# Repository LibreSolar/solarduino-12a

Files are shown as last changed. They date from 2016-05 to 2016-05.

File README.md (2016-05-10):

# Solarduino_12A
12A MPPT solar charge controller based on Arduino

Features: 
- 12A MPPT charger
- 55V max PV input
- 12V or 24V battery output
- Arduino-compatible (ATmega 328P used)
- Expandable via break-out of unused ports to standard 2.54 pin-pitch headers (e.g. used for display, communication like CAN/RS485, etc.)

Built-in protection:
- Overvoltage
- Undervoltage
- Overcurrent
- PV short circuit
- PV reverse polarity (for max. module open circuit voltage of around 40V)
- Battery reverse polarity (destructive, fuse is blown)

# Roadmap
- This is the new version of the charge controller. First PCB was sent to production beginning of May 2016. First test results end of May expected.

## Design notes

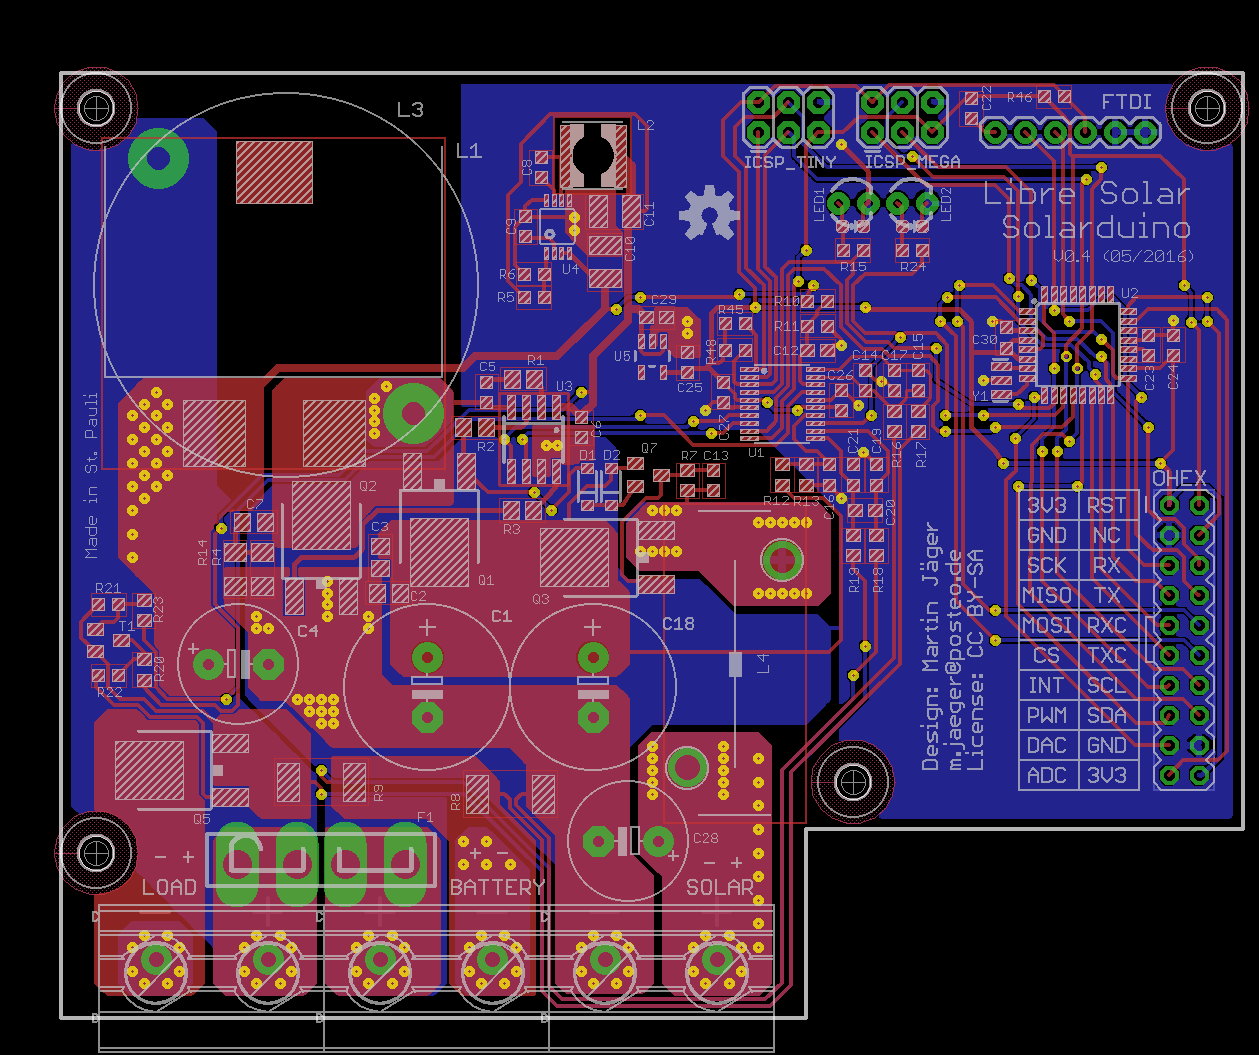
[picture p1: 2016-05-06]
Solarduino_V0.4.png

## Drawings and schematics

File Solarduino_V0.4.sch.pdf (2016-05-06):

A

A

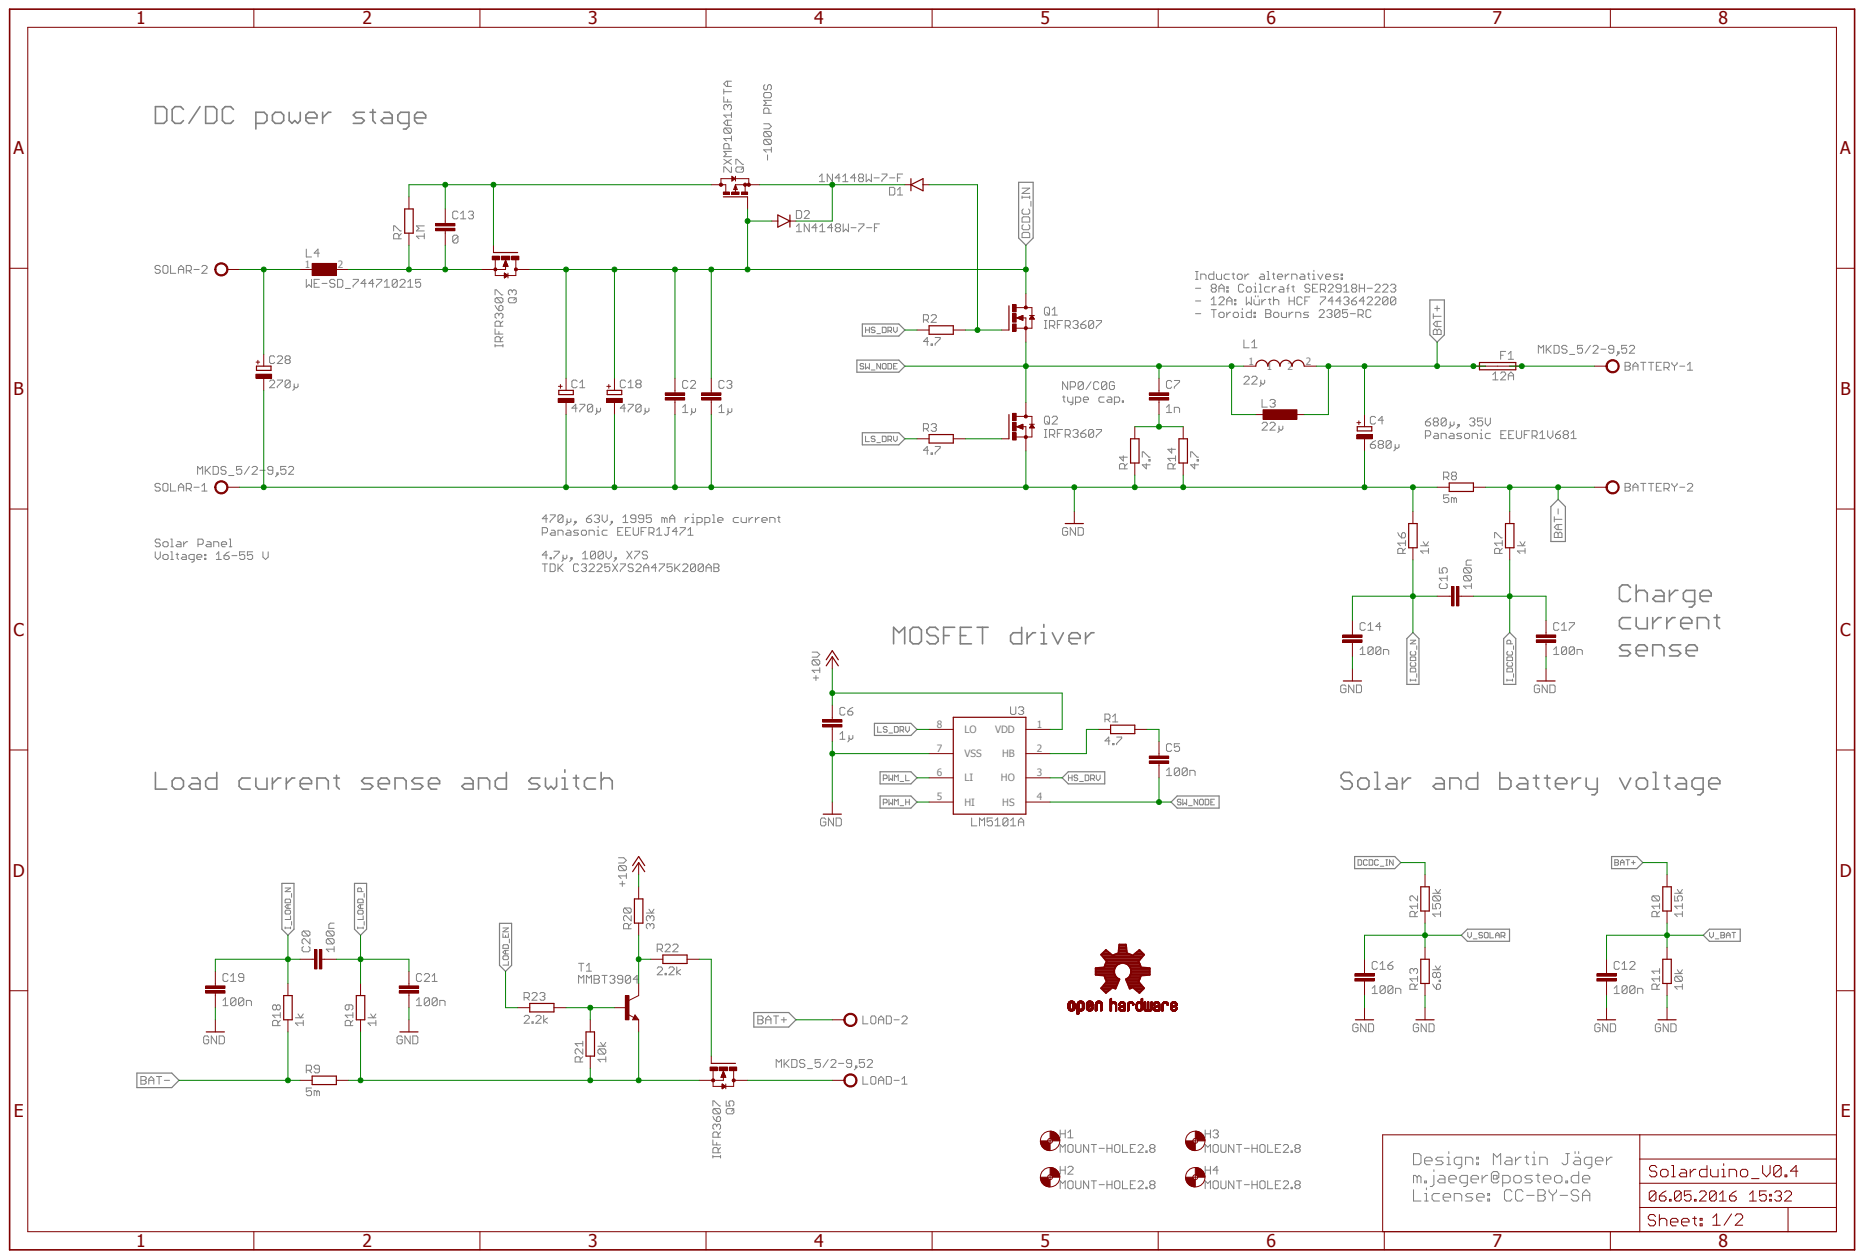
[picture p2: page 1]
VSS; 8 VDD

A

A

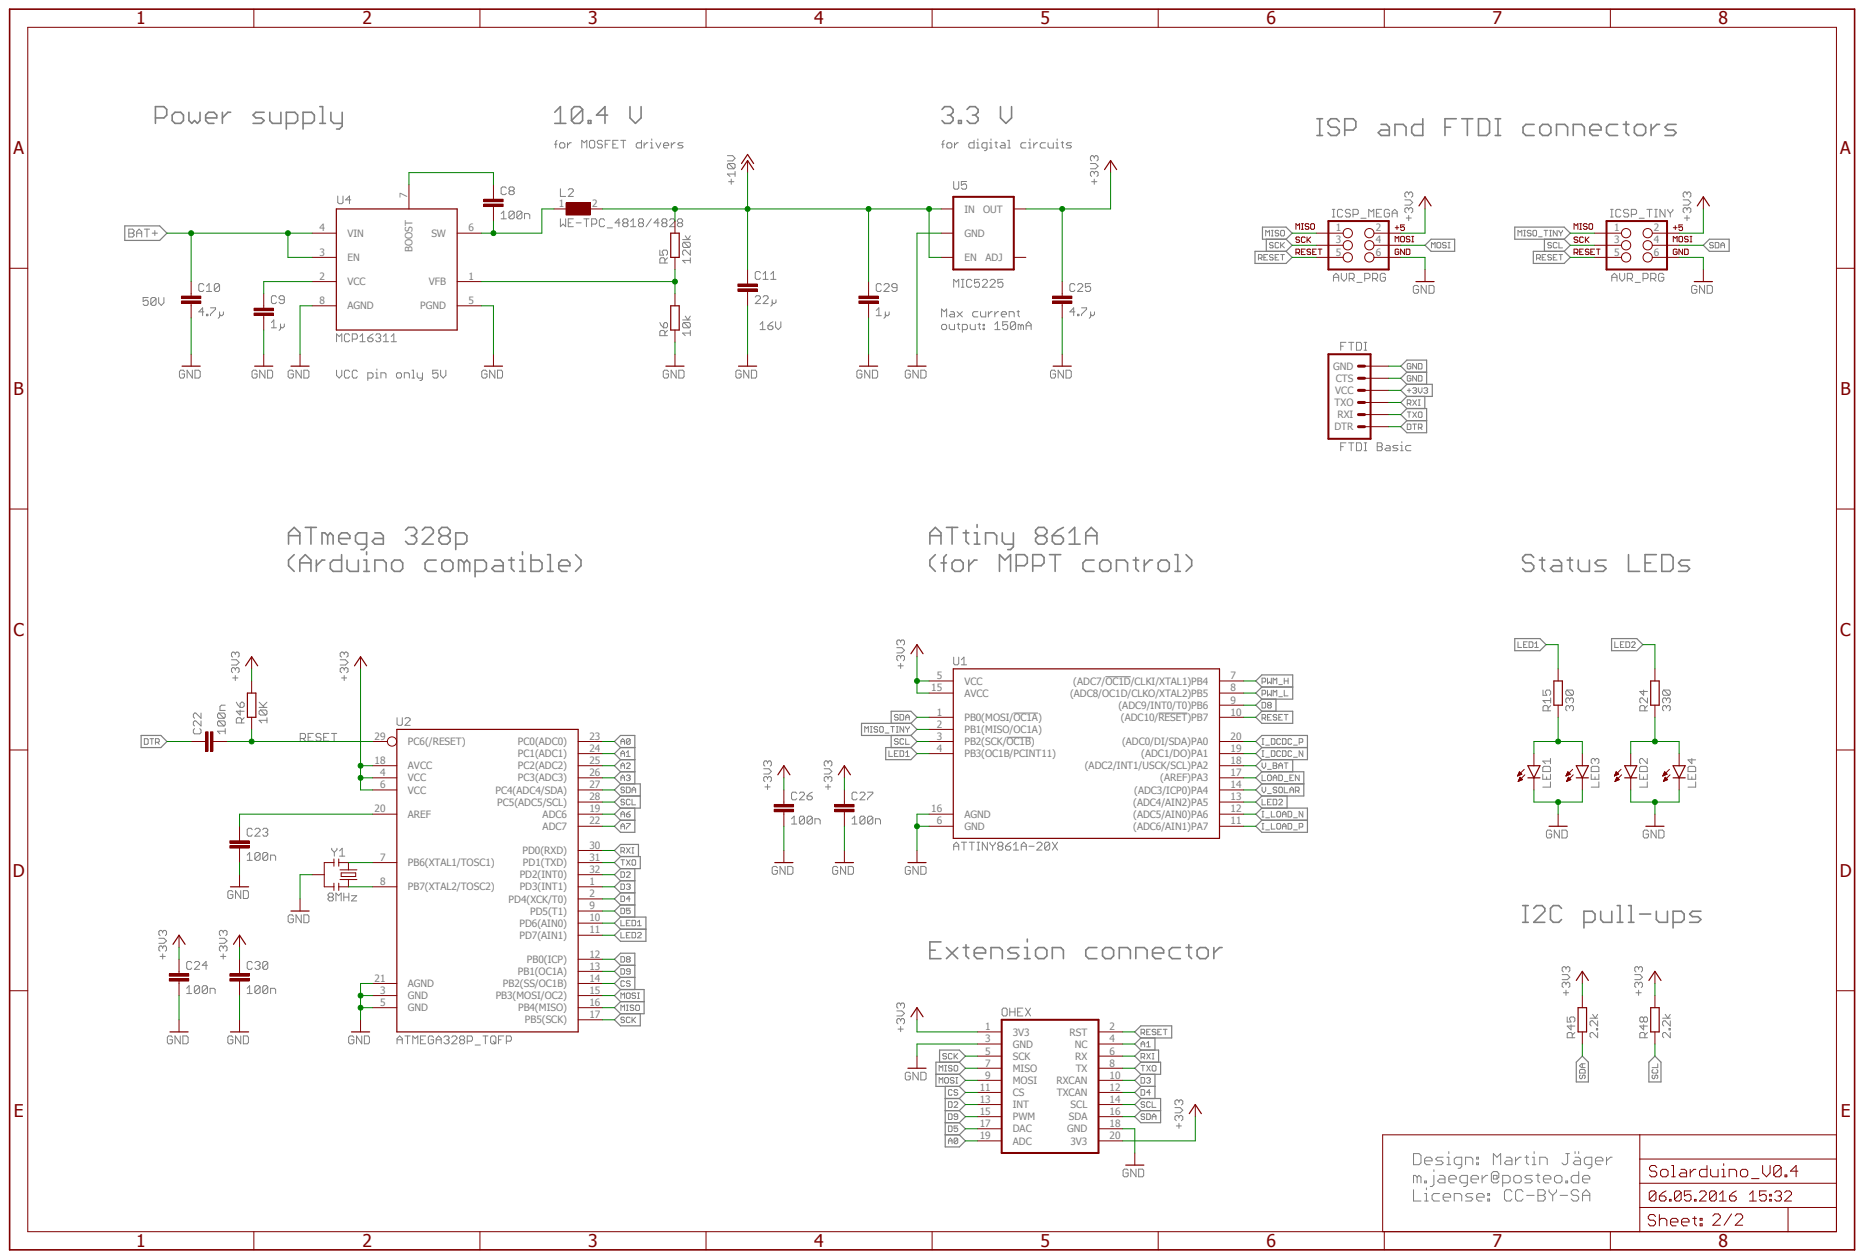
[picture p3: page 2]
DTR; RXI; TXO; VCC; CTS; GND; VFB; 1 VCC; VIN; PGND; BOOST; AGND; (ADC3/ICP0)PA4; (ADC4/AIN2)PA5; (ADC5/AIN0)PA6; (ADC6/AIN1)PA7; (AREF)PA3; 17 (ADC2/INT1/USCK/SCL)PA2; 18 (ADC1/DO)PA1; 19 (ADC0/DI/SDA)PA0; (ADC10/RESET)PB7; 10 (ADC9/INT0/T0)PB6; 9 (ADC8/OC1D/CLKO/XTAL2)PB5; 8 (ADC7/OC1D/CLKI/XTAL1)PB4; AVCC 15; AGND 16; PB0(MOSI/OC1A); PB1(MISO/OC1A); PB2(SCK/OC1B); PB3(OC1B/PCINT11); PB5(SCK); PB7(XTAL2/TOSC2); PB6(XTAL1/TOSC1); AGND 21; AREF 20; AVCC 18; PB4(MISO); 16 PB3(MOSI/OC2)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

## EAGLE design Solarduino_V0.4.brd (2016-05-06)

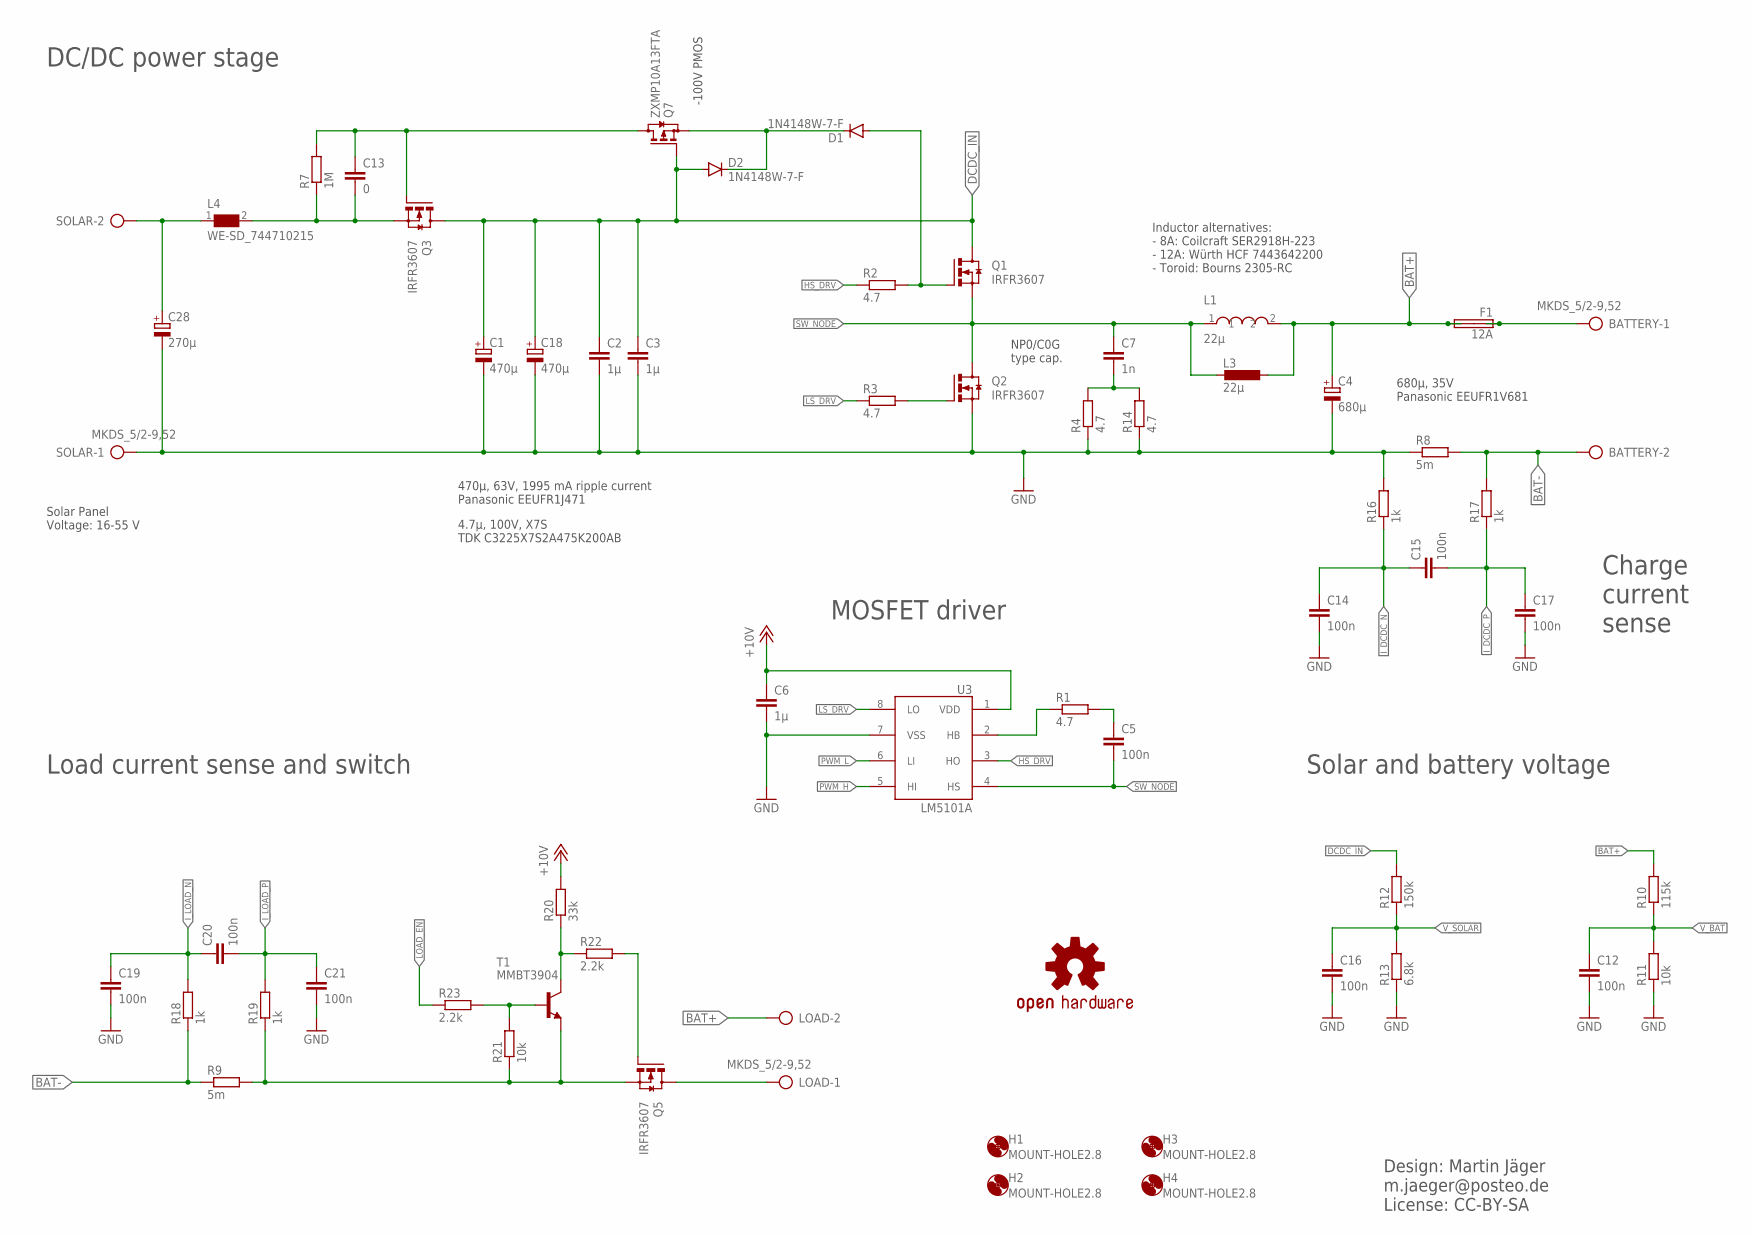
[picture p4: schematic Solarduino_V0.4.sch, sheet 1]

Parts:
BATTERY: MKDS_5/2-9,52; MKDS_5/2-952
C1, C18: 470µ; E5-13; MPN EEUFR1J331B
C2, C3: 1µ; C0805; MPN C3225X7S2A475K200AB
C4: 680µ; E5-10,5; MPN EEUFR1E821B
C5, C12, C14, C15, C16, C17, C19, C20, C21: 100n; C0603; MPN 08055C104KAT2A
C6: 1µ; C0603; MPN 08055C104KAT2A
C7: 1n; C0805; MPN 08055C104KAT2A
C13: 0; C0603; MPN 08055C104KAT2A
C28: 270µ; E5-10,5; MPN EEUFR1E821B
D1, D2: 1N4148W-7-F; SOD-123
F1: 12A; BLADE_FUSE_STD
H1, H2, H3, H4: MOUNT-HOLE2.8; 2,8
L1: 22µ; WE-HCF_2818_7443643300; MPN SER2918H-223KL
L3: 22µ; L-BOURNS-2300-H
L4: WE-SD_744710215
LOAD: MKDS_5/2-9,52; MKDS_5/2-952
N1: OSHW-LOGOM; OSHW-LOGO-M
Q1, Q2, Q3, Q5: IRFR3607; DPAK
Q7: ZXMP10A13FTA; SOT23; MPN BSS84-7-F
R1: 4.7; R0805; MPN CR0805-FX-1001ELF
R2, R3: 4.7; R0805; MPN CR0805-FX-1004ELF.
R4, R14: 4.7; R1206; MPN CRM2010-JW-2R2ELF
R7: 1M; R0603; MPN CR0805-FX-1004ELF.
R8, R9: 5m; R2512; MPN CRF2512-FX-R005ELF
R10: 115k; R0603; MPN ERA6AEB104V
R11: 10k; R0603; MPN ERA6AEB682V
R12: 150k; R0603; MPN ERA6AEB104V
R13: 6.8k; R0603; MPN ERA6AEB104V
R16, R17, R18, R19: 1k; R0603; MPN CRM2010-JW-2R2ELF
R20: 33k; R0603; MPN CRM2010-JW-2R2ELF
R21: 10k; R0603; MPN CRM2010-JW-2R2ELF
R22, R23: 2.2k; R0603; MPN CR0805-FX-1004ELF.
SOLAR: MKDS_5/2-9,52; MKDS_5/2-952
T1: MMBT3904; SOT23-BEC
U3: LM5101A; SOIC-8-N

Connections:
+10V: C6.1, R20.2, U3.1 (VDD); also elsewhere on the board
BAT+: C4.+, F1.P$3 (2A), F1.P$4 (2B), L1.2, L3.P$1 (1), LOAD.2, R10.2; also elsewhere on the board
BAT-: BATTERY.2, R8.2, R9.1, R17.2, R18.1
DCDC_IN: C1.+, C2.1, C3.1, C18.+, D2.A, Q1.4 (D), Q3.4 (D), Q7.1 (G), R12.2
FUSE+: BATTERY.1, F1.P$1 (1A), F1.P$2 (1B)
GND: C1.-, C2.2, C3.2, C4.-, C6.2, C12.2, C14.2, C16.2, C17.2, C18.-, C19.2, C21.2, C28.-, Q2.3 (S), R4.1, R8.1, R11.1, R13.1, R14.1, R16.2, SOLAR.1, U3.7 (VSS); also elsewhere on the board
HS_DRV: R2.1, U3.3 (HO)
I_DCDC_N: C14.1, C15.1, R16.1; also elsewhere on the board
I_DCDC_P: C15.2, C17.1, R17.1; also elsewhere on the board
I_LOAD_N: C19.1, C20.1, R18.2; also elsewhere on the board
I_LOAD_P: C20.2, C21.1, R19.2; also elsewhere on the board
LC_OUT: C13.2, L4.2, Q3.3 (S), R7.1
LOAD-: LOAD.1, Q5.4 (D)
LOAD_EN: R23.1; also elsewhere on the board
LOAD_G: Q5.1 (G), R22.2
LS_DRV: R3.1, U3.8 (LO)
unnamed: R1.1, U3.2 (HB)
unnamed: C5.1, R1.2
unnamed: D1.A, Q1.1 (G), R2.2
unnamed: Q5.3 (S), R9.2, R19.1, R21.1, T1.E
unnamed: C13.1, Q3.1 (G), Q7.3 (D), R7.2
unnamed: Q2.1 (G), R3.2
unnamed: D1.C, D2.C, Q7.2 (S)
unnamed: R20.1, R22.1, T1.C
unnamed: C7.2, R4.2, R14.2
unnamed: R21.2, R23.2, T1.B
PWM_H: U3.5 (HI); also elsewhere on the board
PWM_L: U3.6 (LI); also elsewhere on the board
SOLAR+: C28.+, L4.1, SOLAR.2
SW_NODE: C5.2, C7.1, L1.1, L3.P$2 (2), Q1.3 (S), Q2.4 (D), U3.4 (HS)
V_BAT: C12.1, R10.1, R11.2; also elsewhere on the board
V_SOLAR: C16.1, R12.1, R13.2; also elsewhere on the board

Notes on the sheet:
470µ, 63V, 1995 mA ripple current Panasonic EEUFR1J471
680µ, 35V Panasonic EEUFR1V681
Solar Panel Voltage: 16-55 V
Design: Martin Jäger m.jaeger@posteo.de License: CC-BY-SA
DC/DC power stage
4.7µ, 100V, X7S TDK C3225X7S2A475K200AB
Inductor alternatives: - 8A: Coilcraft SER2918H-223 - 12A: Würth HCF 7443642200 - Toroid: Bourns 2305-RC
-100V PMOS
NP0/C0G type cap.
Load current sense and switch
Charge current sense
MOSFET driver
Solar and battery voltage

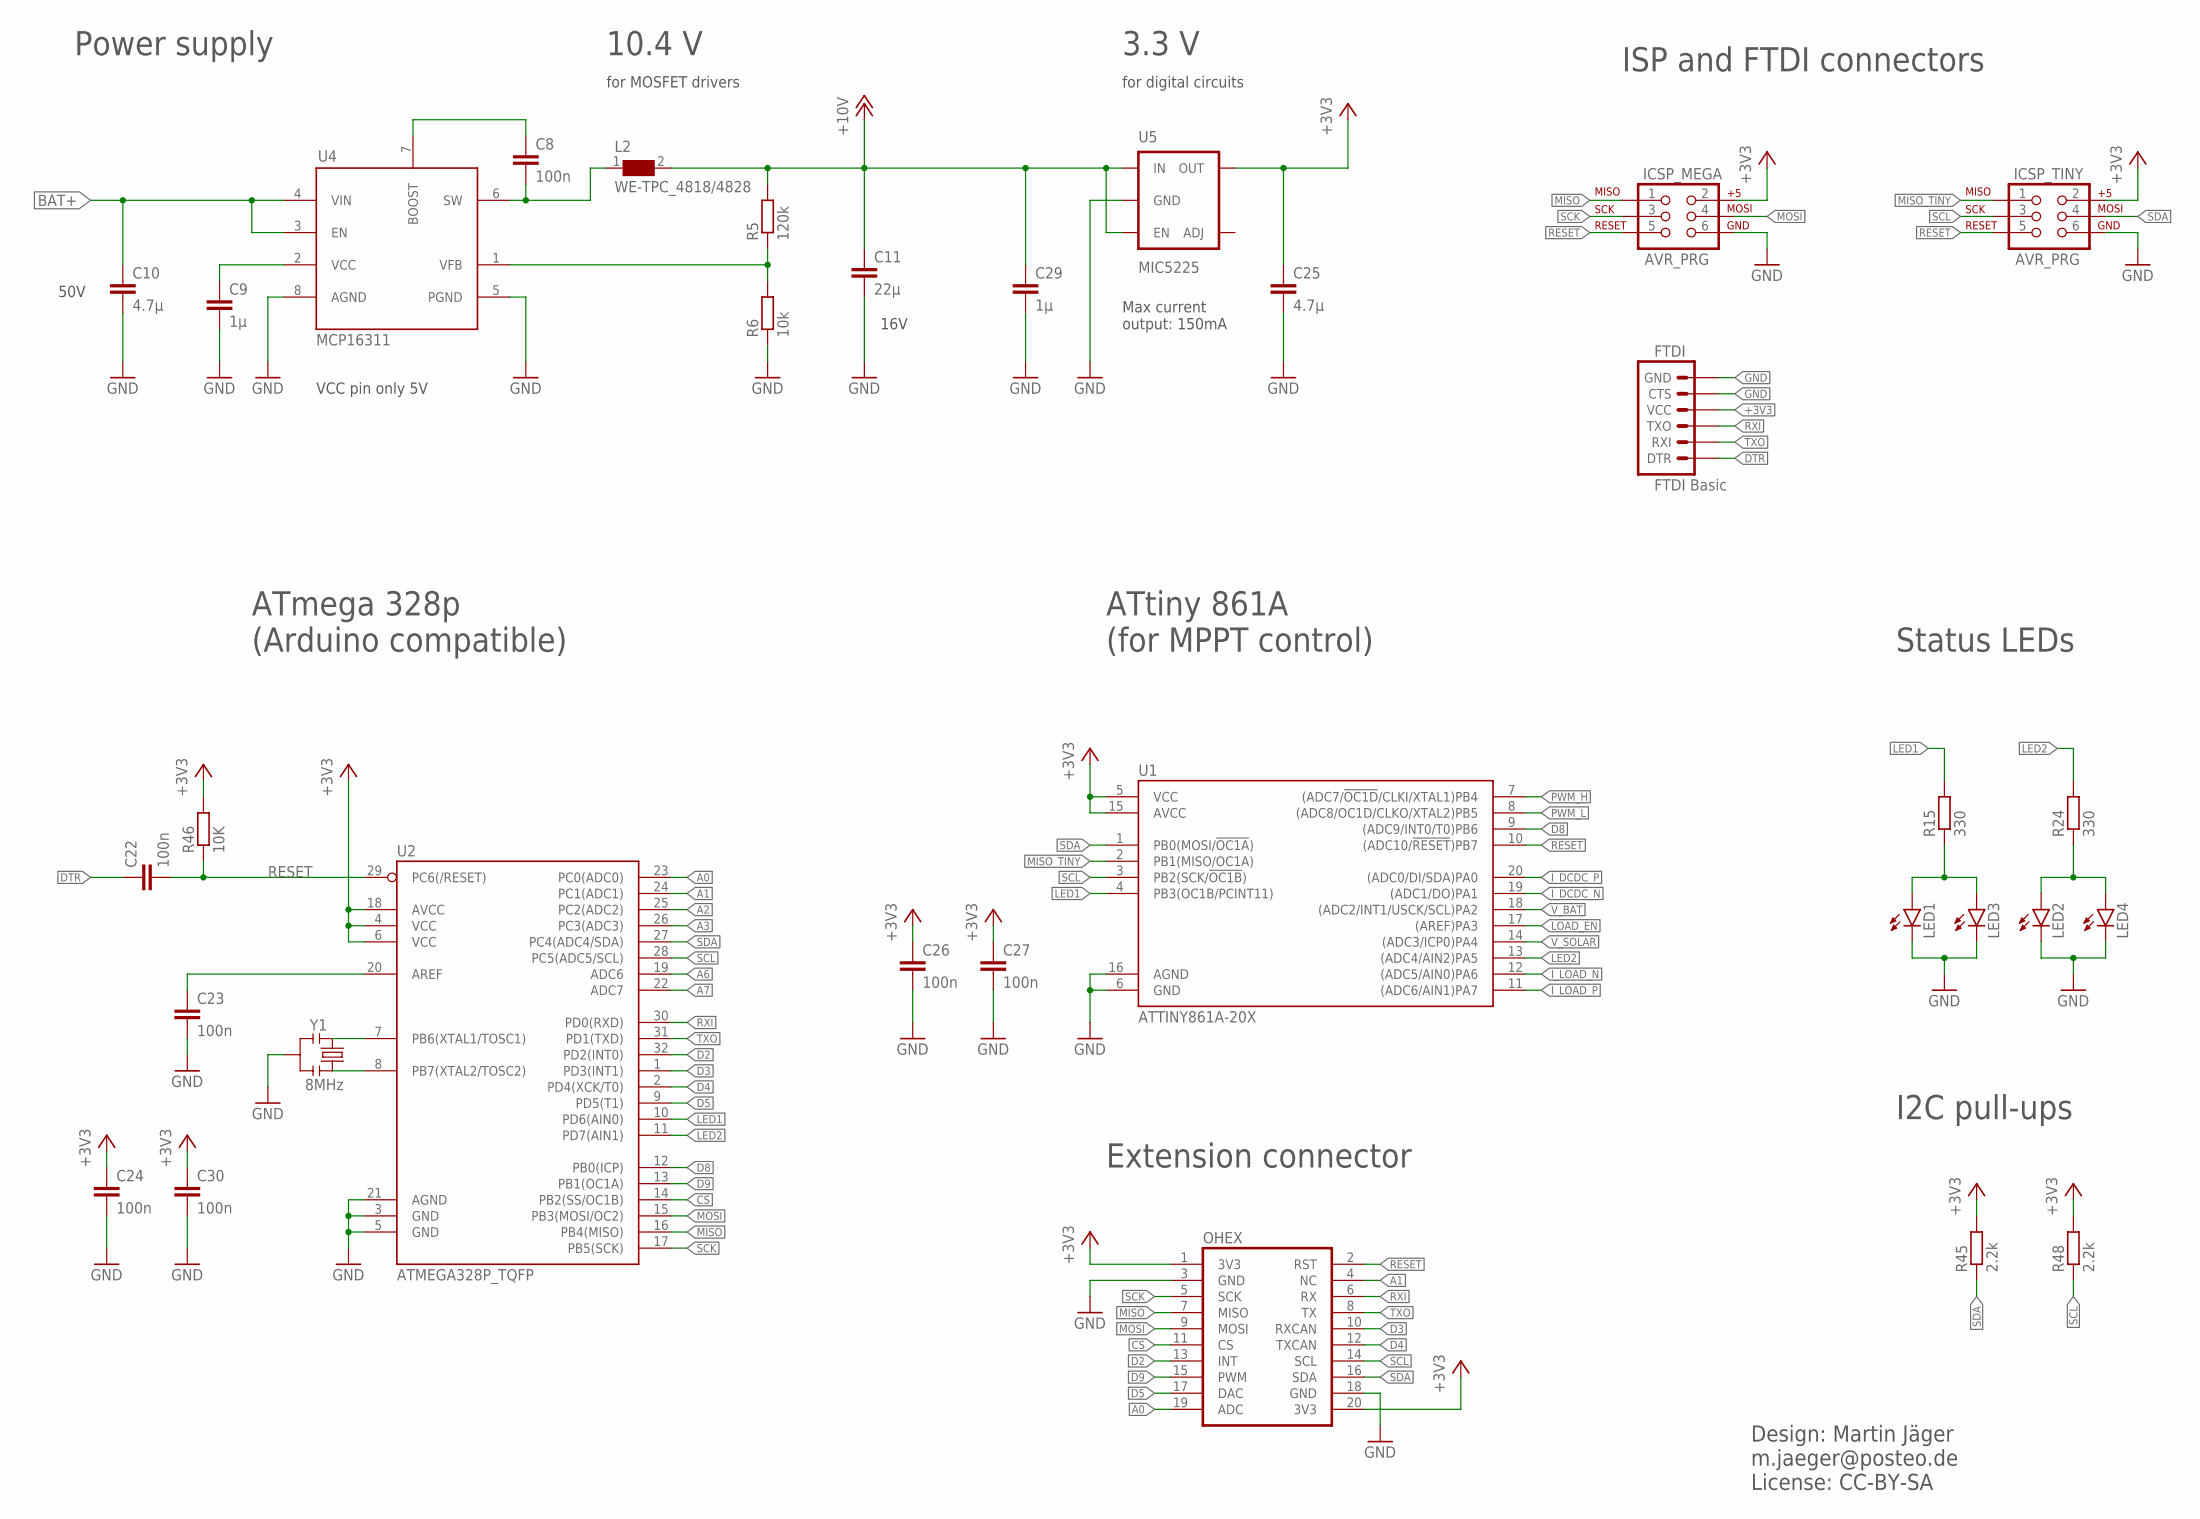
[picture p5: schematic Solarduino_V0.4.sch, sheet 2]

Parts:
C8, C22, C23, C24, C26, C27, C30: 100n; C0603; MPN 08055C104KAT2A
C9: 1µ; C0603; MPN 08055C104KAT2A
C10: 4.7µ; C1210; MPN 08055C104KAT2A
C11: 22µ; C1210; MPN 08055C104KAT2A
C25: 4.7µ; C0603; MPN 0805YC475KAT2A
C29: 1µ; C0603; MPN 08053C105KAT2A
FTDI: FTDI Basic; 1X06; MPN 2212S-06SG-85
ICSP_MEGA: AVR_PRG; 2X3
ICSP_TINY: AVR_PRG; 2X3
L2: WE-TPC_4818/4828
LED1, LED2: LED3MM
LED3, LED4: LED0603; LED-0603
OHEX: OHEX; OHEX_SMALL
R5: 120k; R0603; MPN CR0805-FX-1001ELF
R6: 10k; R0603; MPN CR0805-FX-1001ELF
R15, R24: 330; R0603; MPN MCMR06X1001FTL
R45, R48: 2.2k; R0603; MPN CR0805-FX-1001ELF
R46: 10K; R0603; MPN CR0805-FX-1002ELF
U1: ATTINY861A-20X; TSSOP20
U2: ATMEGA328P_TQFP; TQFP32-08
U4: MCP16311; MSOP8
U5: MIC5225; SOT23-5; MPN MIC5225-3.3YM5-TR
Y1: 8MHz; RESONATOR-SMD; MPN CSTCE8M00G55-R0

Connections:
+3V3: C24.1, C25.1, C26.1, C27.1, C30.1, FTDI.4 (VCC), ICSP_MEGA.2, ICSP_TINY.2, OHEX.1 (3V3), OHEX.20 (3V3), R45.2, R46.2, R48.2, U1.5 (VCC), U1.15 (AVCC), U2.4 (VCC), U2.6 (VCC), U2.18 (AVCC), U5.5 (OUT)
+10V: C11.1, C29.1, L2.2, R5.2, U5.1 (IN), U5.3 (EN); also elsewhere on the board
A0: OHEX.19 (ADC), U2.23 (PC0(ADC0))
A1: OHEX.4 (NC), U2.24 (PC1(ADC1))
A2: U2.25 (PC2(ADC2))
A3: U2.26 (PC3(ADC3))
A6: U2.19 (ADC6)
A7: U2.22 (ADC7)
AREF: C23.1, U2.20 (AREF)
BAT+: C10.1, U4.3 (EN), U4.4 (VIN); also elsewhere on the board
CS: OHEX.11 (CS), U2.14 (PB2(SS/OC1B))
D2: OHEX.13 (INT), U2.32 (PD2(INT0))
D3: OHEX.10 (RXCAN), U2.1 (PD3(INT1))
D4: OHEX.12 (TXCAN), U2.2 (PD4(XCK/T0))
D5: OHEX.17 (DAC), U2.9 (PD5(T1))
D8: U1.9 ((ADC9/INT0/T0)PB6), U2.12 (PB0(ICP))
D9: OHEX.15 (PWM), U2.13 (PB1(OC1A))
DTR: C22.1, FTDI.1 (DTR)
GND: C9.2, C10.2, C11.2, C23.2, C24.2, C25.2, C26.2, C27.2, C29.2, C30.2, FTDI.5 (CTS), FTDI.6 (GND), ICSP_MEGA.6, ICSP_TINY.6, LED1.K (C), LED2.K (C), LED3.C, LED4.C, OHEX.3 (GND), OHEX.18 (GND), R6.1, U1.6 (GND), U1.16 (AGND), U2.3 (GND), U2.5 (GND), U2.21 (AGND), U4.5 (PGND), U4.8 (AGND), U5.2 (GND), Y1.2; also elsewhere on the board
I_DCDC_N: U1.19 ((ADC1/DO)PA1); also elsewhere on the board
I_DCDC_P: U1.20 ((ADC0/DI/SDA)PA0); also elsewhere on the board
I_LOAD_N: U1.12 ((ADC5/AIN0)PA6); also elsewhere on the board
I_LOAD_P: U1.11 ((ADC6/AIN1)PA7); also elsewhere on the board
LED1: R15.2, U1.4 (PB3(OC1B/PCINT11)), U2.10 (PD6(AIN0))
LED2: R24.2, U1.13 ((ADC4/AIN2)PA5), U2.11 (PD7(AIN1))
LOAD_EN: U1.17 ((AREF)PA3); also elsewhere on the board
MISO: ICSP_MEGA.1, OHEX.7 (MISO), U2.16 (PB4(MISO))
MISO_TINY: ICSP_TINY.1, U1.2 (PB1(MISO/OC1A))
MOSI: ICSP_MEGA.4, OHEX.9 (MOSI), U2.15 (PB3(MOSI/OC2))
unnamed: C8.2, L2.1, U4.6 (SW)
unnamed: C8.1, U4.7 (BOOST)
unnamed: U2.7 (PB6(XTAL1/TOSC1)), Y1.1
unnamed: C9.1, U4.2 (VCC)
unnamed: U2.8 (PB7(XTAL2/TOSC2)), Y1.3
unnamed: R5.1, R6.2, U4.1 (VFB)
unnamed: LED1.A, LED3.A, R15.1
unnamed: LED2.A, LED4.A, R24.1
PWM_H: U1.7 ((ADC7/!OC1D!/CLKI/XTAL1)PB4); also elsewhere on the board
PWM_L: U1.8 ((ADC8/OC1D/CLKO/XTAL2)PB5); also elsewhere on the board
RESET: C22.2, ICSP_MEGA.5, ICSP_TINY.5, OHEX.2 (RST), R46.1, U1.10 ((ADC10/!RESET!)PB7), U2.29 (PC6(/RESET))
RXI: FTDI.3 (TXO), OHEX.6 (RX), U2.30 (PD0(RXD))
SCK: ICSP_MEGA.3, OHEX.5 (SCK), U2.17 (PB5(SCK))
SCL: ICSP_TINY.3, OHEX.14 (SCL), R48.1, U1.3 (PB2(SCK/!OC1B!)), U2.28 (PC5(ADC5/SCL))
SDA: ICSP_TINY.4, OHEX.16 (SDA), R45.1, U1.1 (PB0(MOSI/!OC1A!)), U2.27 (PC4(ADC4/SDA))
TXO: FTDI.2 (RXI), OHEX.8 (TX), U2.31 (PD1(TXD))
V_BAT: U1.18 ((ADC2/INT1/USCK/SCL)PA2); also elsewhere on the board
V_SOLAR: U1.14 ((ADC3/ICP0)PA4); also elsewhere on the board

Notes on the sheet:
Power supply
Max current output: 150mA
Design: Martin Jäger m.jaeger@posteo.de License: CC-BY-SA
16V
50V
VCC pin only 5V
Status LEDs
ATmega 328p (Arduino compatible)
ATtiny 861A (for MPPT control)
Extension connector
ISP and FTDI connectors
I2C pull-ups
10.4 V
3.3 V
for MOSFET drivers
for digital circuits

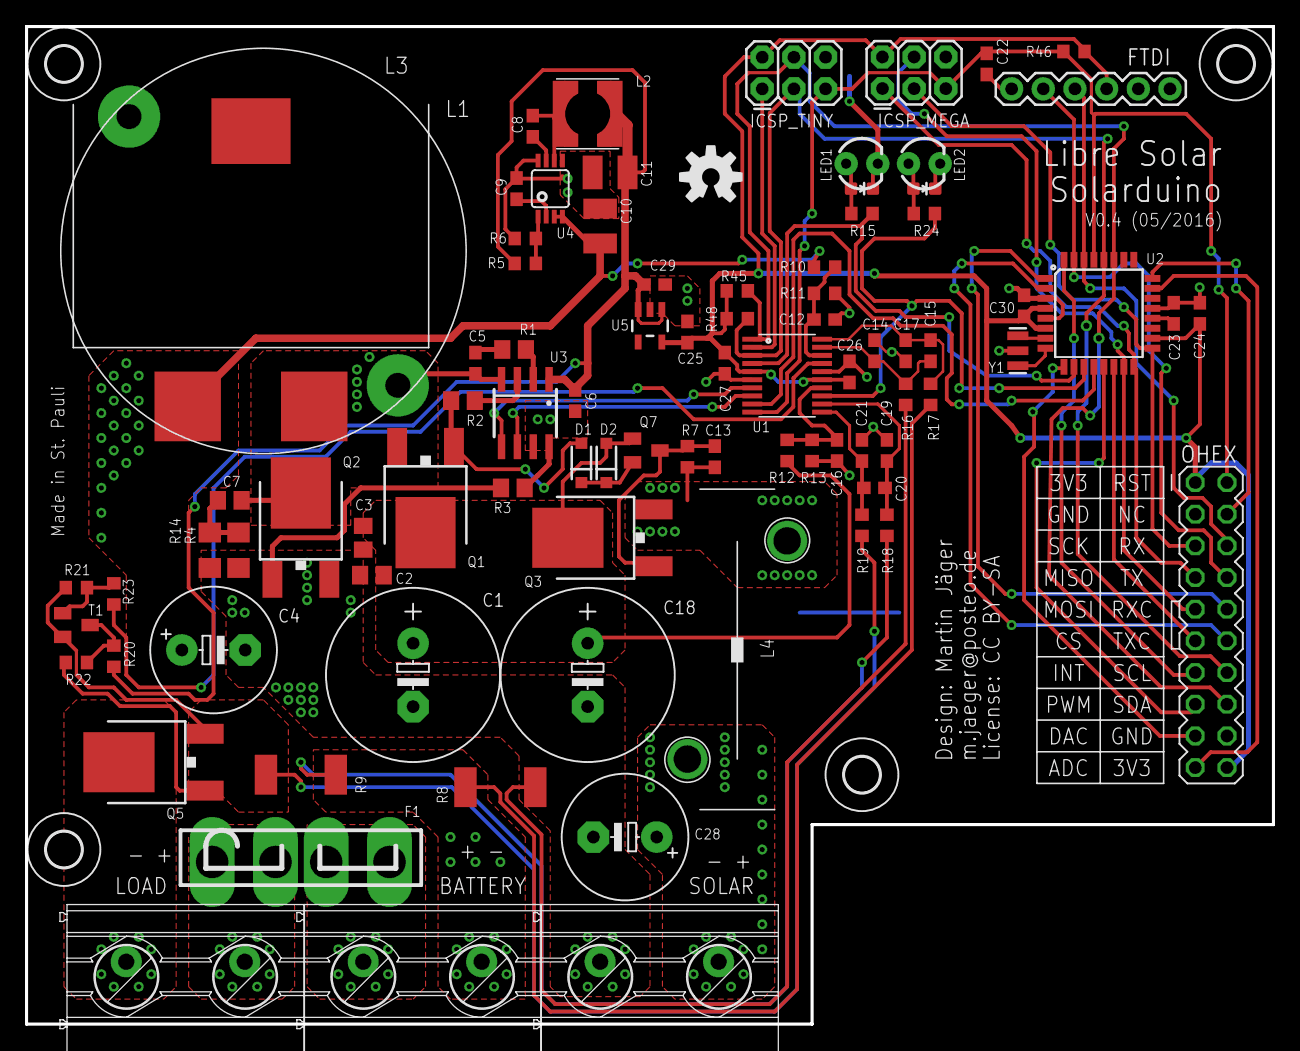
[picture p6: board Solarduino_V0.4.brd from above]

Board: 2 copper layers, 100.0 x 80.0 mm, 92 parts (0 on the bottom side), 63 nets.

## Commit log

2016-05-06 Initial upload of board to be manufactured by aisler.net
    [Solarduino_V0.4.brd, Solarduino_V0.4.sch]
2016-05-06 Added PDF and PNG of schematic and board

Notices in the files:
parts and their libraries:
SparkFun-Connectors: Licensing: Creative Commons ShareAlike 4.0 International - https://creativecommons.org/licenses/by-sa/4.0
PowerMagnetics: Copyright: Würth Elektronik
